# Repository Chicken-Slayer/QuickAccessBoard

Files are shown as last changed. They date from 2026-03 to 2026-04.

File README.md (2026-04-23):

# QuickAccessBoard
This is a 12 key macropad that makes use of a rotary encoder and an OLED display. The body was designed in Fusion, and it uses KMK firmware.

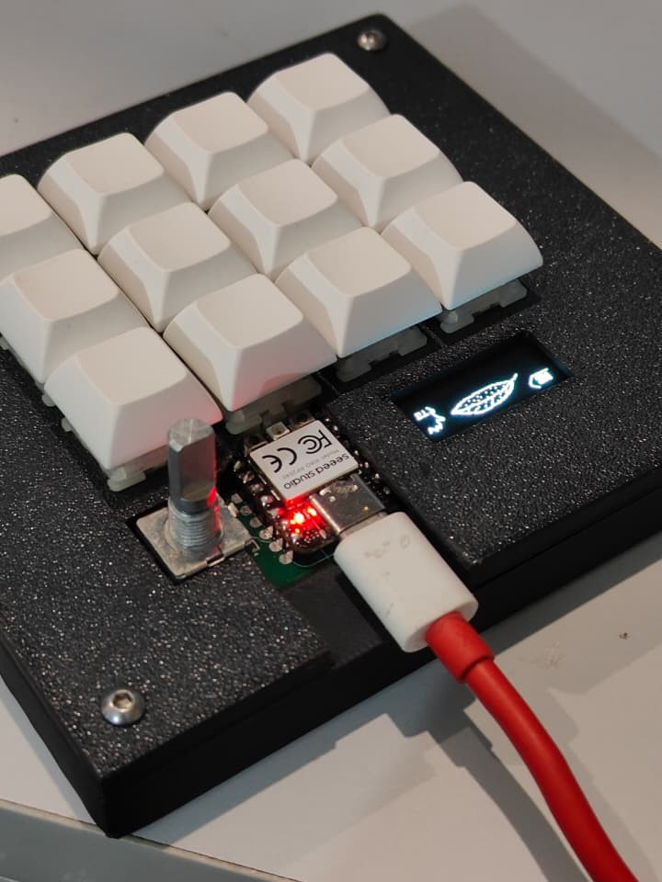
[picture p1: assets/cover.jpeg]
cover


## Features:
- 128x32 OLED Display
- EC11 Rotary Encoder
- 12 Keys

## PCB:
Here's the PCB:

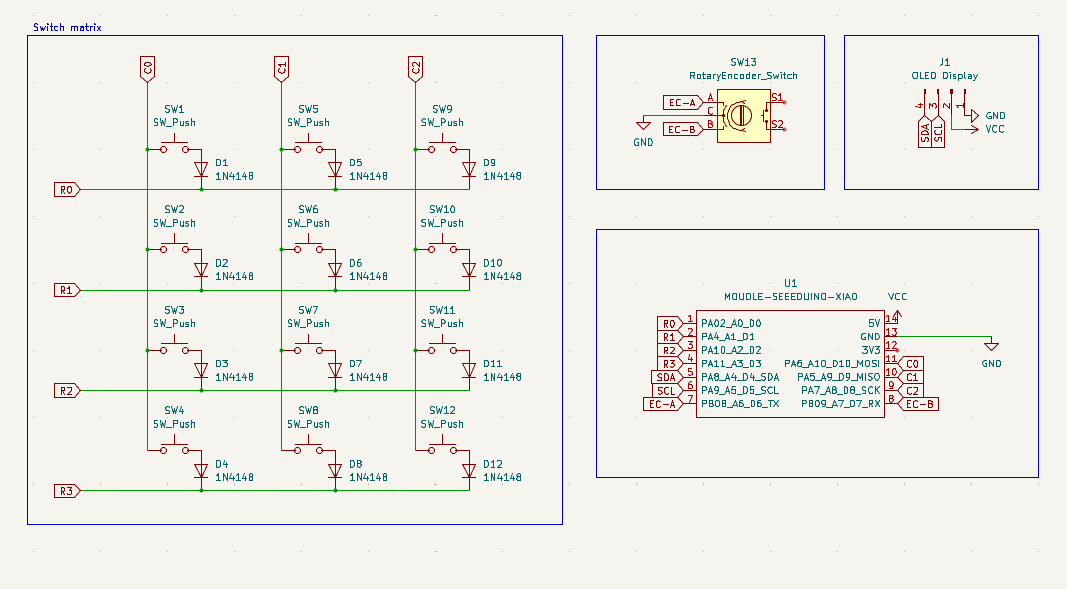
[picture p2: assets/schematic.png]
Schematic


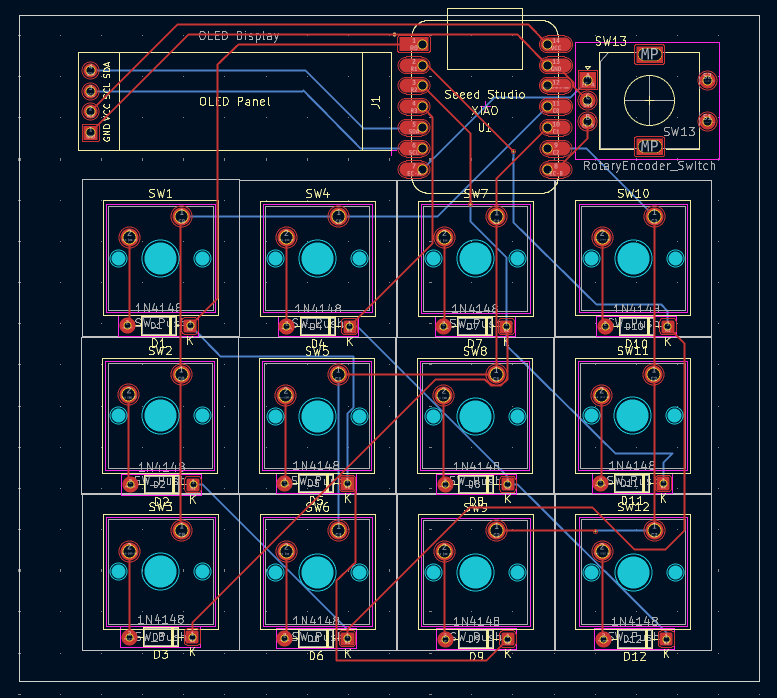
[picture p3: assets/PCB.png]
PCB


## CAD Model:
The case is secured using 4 M3 bolts and heatset inserts. The PCB is held in place in a sandwich arrangement.

It has two separate printed pieces: the base, and the top cover. 

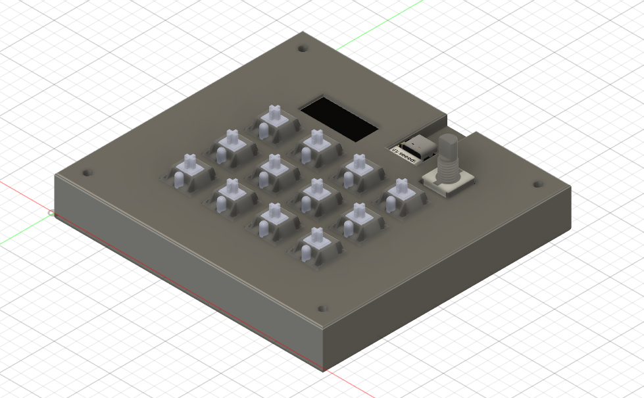
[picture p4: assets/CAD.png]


Made in Fusion.

## Firmware Overview
This hackpad uses [KMK](https://github.com/KMKfw/kmk_firmware) firmware for everything. A key matrix is defined in the code, and various macros are assigned to different keys, as well as media control, brightness controls, and setup for an OLED display. The display by default shows a static image, and goes into sleep mode when the keyboard is not in use. 

It can be easily modified to accomodate other macros and the OLED display image can also be easily swapped out for another, or even an animation quite easily.

## BOM:
Here should be everything you need to make this hackpad

- 12x Cherry MX Switches
- 12x DSA Keycaps
- 4x M3x5x4 Heatset inserts
- 4x M3x16mm SHCS Bolts
- 12x 1N4148 DO-35 Diodes.
- 1x 0.91" 128x32 OLED Display
- 1x EC11 Rotary Encoder
- 1x XIAO RP2040
- 1x Case (2 printed parts)

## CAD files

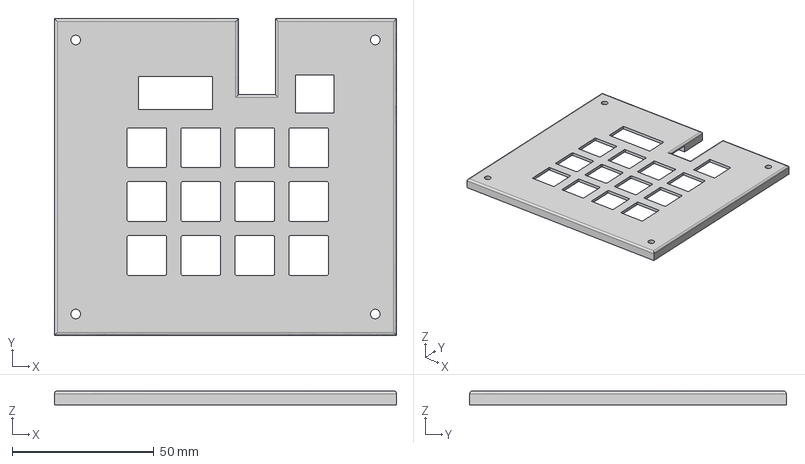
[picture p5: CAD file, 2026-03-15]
production/TOP.step
120.8 x 111.8 x 5.00 mm

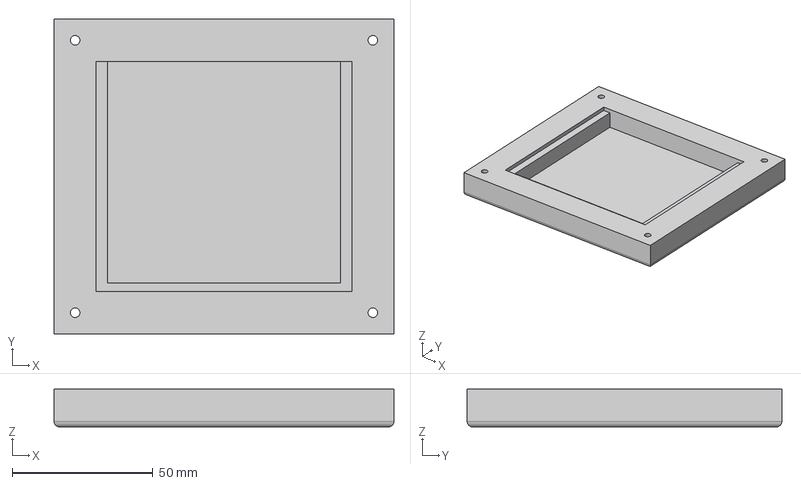
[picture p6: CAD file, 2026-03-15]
production/BOTTOM.step
120.8 x 111.8 x 13.5 mm

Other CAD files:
CAD/QuickAccessBoard.f3z

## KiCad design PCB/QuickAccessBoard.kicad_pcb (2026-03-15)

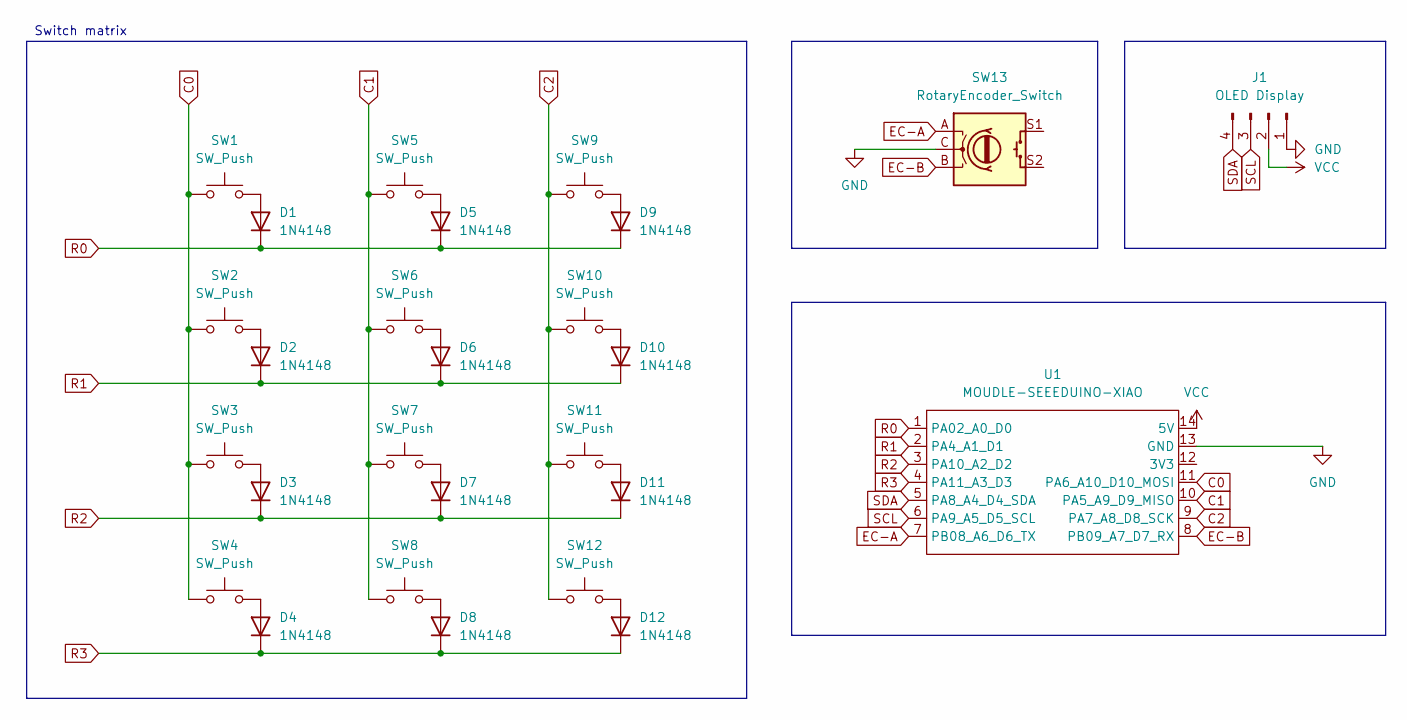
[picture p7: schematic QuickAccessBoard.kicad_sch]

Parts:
D1, D2, D3, D4, D5, D6, D7, D8, D9, D10, D11, D12: 1N4148; D_DO-35_SOD27_P7.62mm_Horizontal
J1: OLED Display; SSD1306-0.91-OLED-4pin-128x32
SW1, SW2, SW3, SW4, SW5, SW6, SW7, SW8, SW9, SW10, SW11, SW12: SW_Push; SW_Cherry_MX_1.00u_PCB
SW13: RotaryEncoder_Switch; RotaryEncoder_Alps_EC11E-Switch_Vertical_H20mm
U1: MOUDLE-SEEEDUINO-XIAO; XIAO-Generic-Hybrid-14P-2.54-21X17.8MM

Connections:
C0: SW1.1, SW2.1, SW3.1, SW4.1, U1.11 (PA6_A10_D10_MOSI)
C1: SW5.1, SW6.1, SW7.1, SW8.1, U1.10 (PA5_A9_D9_MISO)
C2: SW9.1, SW10.1, SW11.1, SW12.1, U1.9 (PA7_A8_D8_SCK)
EC-A: SW13.A, U1.7 (PB08_A6_D6_TX)
EC-B: SW13.B, U1.8 (PB09_A7_D7_RX)
GND: J1.1, SW13.C, U1.13 (GND)
unnamed: D1.2 (A), SW1.2
unnamed: D2.2 (A), SW2.2
unnamed: D3.2 (A), SW3.2
unnamed: D4.2 (A), SW4.2
unnamed: D5.2 (A), SW5.2
unnamed: D6.2 (A), SW6.2
unnamed: D7.2 (A), SW7.2
unnamed: D8.2 (A), SW8.2
unnamed: D9.2 (A), SW9.2
unnamed: D10.2 (A), SW10.2
unnamed: D11.2 (A), SW11.2
unnamed: D12.2 (A), SW12.2
R0: D1.1 (K), D5.1 (K), D9.1 (K), U1.1 (PA02_A0_D0)
R1: D2.1 (K), D6.1 (K), D10.1 (K), U1.2 (PA4_A1_D1)
R2: D3.1 (K), D7.1 (K), D11.1 (K), U1.3 (PA10_A2_D2)
R3: D4.1 (K), D8.1 (K), D12.1 (K), U1.4 (PA11_A3_D3)
SCL: J1.3, U1.6 (PA9_A5_D5_SCL)
SDA: J1.4, U1.5 (PA8_A4_D4_SDA)
VCC: J1.2, U1.14 (5V)

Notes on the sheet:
Switch matrix

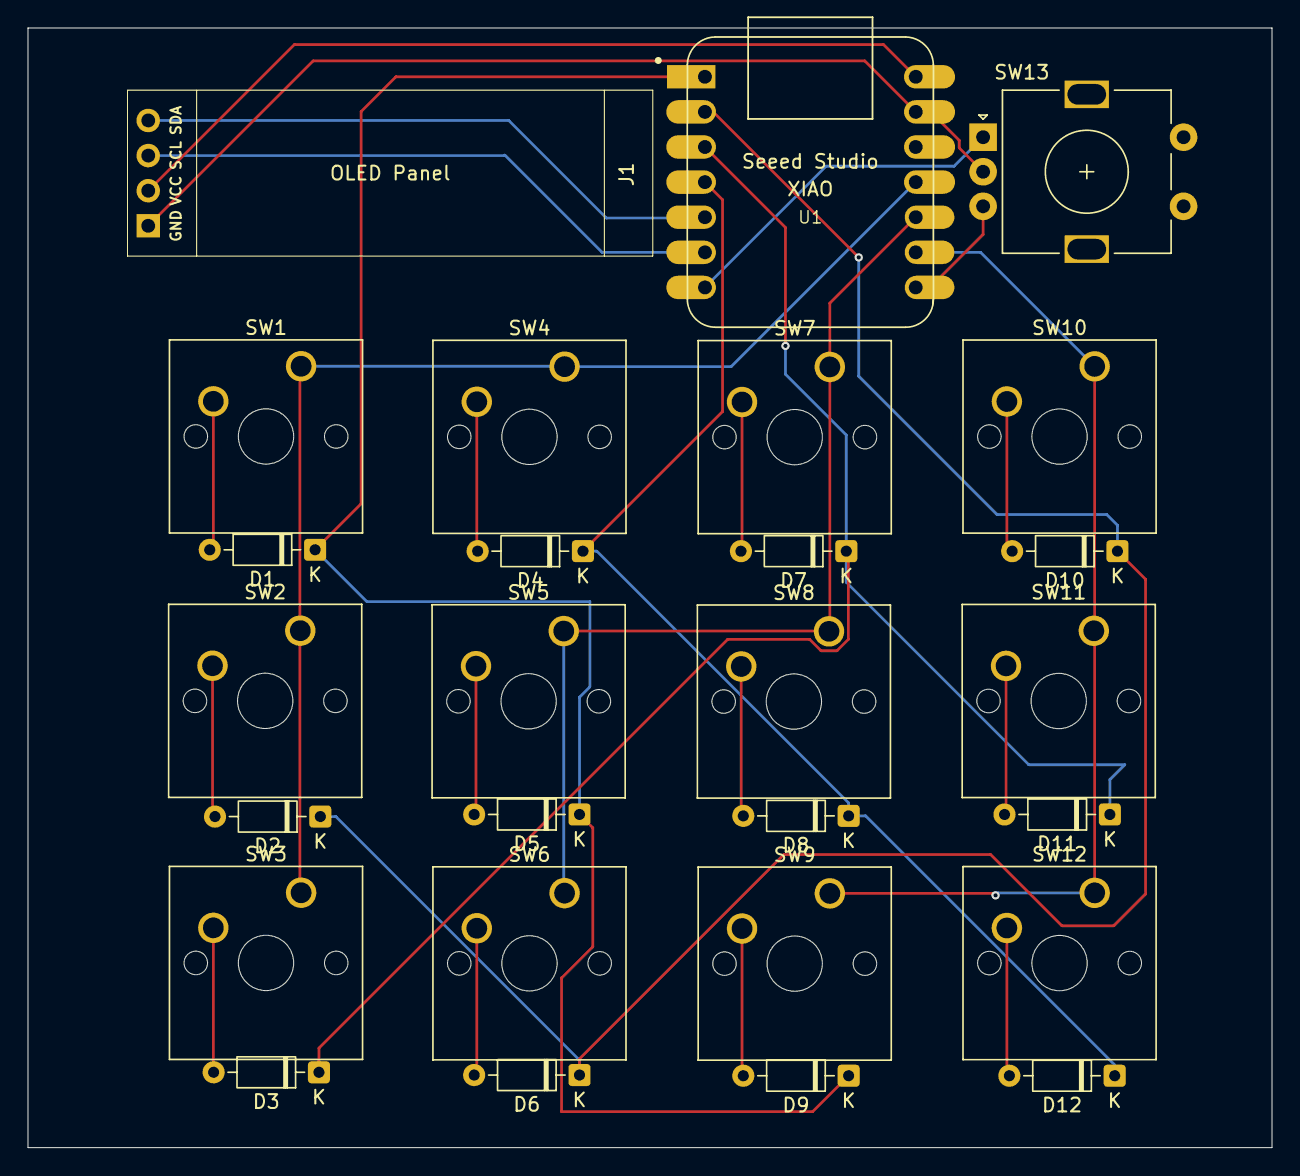
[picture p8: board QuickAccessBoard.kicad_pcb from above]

Board: 2 copper layers, 90.0 x 81.0 mm, 27 parts (0 on the bottom side), 25 nets.

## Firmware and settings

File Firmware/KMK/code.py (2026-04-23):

print("Starting")

import board
import busio

from kmk.kmk_keyboard import KMKKeyboard
from kmk.keys import KC, Key
from kmk.modules.layers import Layers
from kmk.modules.holdtap import HoldTap
from kmk.scanners import DiodeOrientation
from kmk.modules.macros import Macros, UnicodeModeWinC
from kmk.modules.macros import Press, Release, Tap
from kmk.extensions.media_keys import MediaKeys
from kmk.modules.encoder import EncoderHandler
from kmk.extensions.display import Display, TextEntry, ImageEntry
from kmk.extensions.display.ssd1306 import SSD1306
## Keyboard Configuration:

keyboard = KMKKeyboard()
encoder_handler = EncoderHandler()
keyboard.modules.append(encoder_handler)

macros = Macros()
keyboard.modules.append(macros)
keyboard.extensions.append(MediaKeys())
keyboard.col_pins = (board.D10, board.D9, board.D8)
keyboard.row_pins = (board.D0, board.D1, board.D2, board.D3)
keyboard.diode_orientation = DiodeOrientation.COL2ROW

## OLED Configuration:
i2c_bus = busio.I2C(board.SCL, board.SDA)

driver = SSD1306(i2c=i2c_bus)

display = Display(
    # Mandatory:
    display=driver,
    # Optional:
    width=128, # screen size
    height=32, # screen size
    flip = False, # flips your display content
    flip_left = False, # flips your display content on left side split
    flip_right = False, # flips your display content on right side split
    brightness=0.8, # initial screen brightness level
    brightness_step=0.1, # used for brightness increase/decrease keycodes
    dim_time=20, # time in seconds to reduce screen brightness
    dim_target=0.1, # set level for brightness decrease
    off_time=60, # time in seconds to turn off screen
    powersave_dim_time=10, # time in seconds to reduce screen brightness
    powersave_dim_target=0.1, # set level for brightness decrease
    powersave_off_time=30, # time in seconds to turn off screen
)

display.entries = [
    ImageEntry(image="img.bmp", x=0, y=0),
]
keyboard.extensions.append(display)

## Macro Definitions and Keymaps:

macros.unicode_mode = UnicodeModeWinC

## Assign macros to your desired messages here

MSG1 = KC.MACRO("GGWP")
MSG2 = KC.MACRO("Care flank, enemies behind you")
FLIP = KC.MACRO('Hatt')
SHRUG = KC.MACRO('Kya hi kar sakte hai :(')
NICE = KC.MACRO('Nice work team!')
RR = KC.MACRO('https://www.youtube.com/watch?v=dQw4w9WgXcQ')

encoder_handler.pins = (
    # regular direction encoder
    (board.D6, board.D7, None,),
    )

keyboard.keymap = [
    [KC.MUTE, KC.MNXT, KC.MPRV, KC.MPLY, KC.MSTP, MSG1, MSG2, NICE, KC.BRIU, KC.BRID, SHRUG, RR]
]

encoder_handler.map = [ ((KC.VOLU, KC.VOLD),),]

if __name__ == '__main__':
    keyboard.go()

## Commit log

2026-03-15 Structured Project design files
    [QuickAccessBoard.kicad_pcb, QuickAccessBoard.kicad_sch]
2026-03-15 Added production files
    [BOTTOM.step, TOP.step]
2026-03-15 Fixed flaw in PCB
    [QuickAccessBoard.kicad_pcb]
2026-03-16 Fixed README, added CAD source files
    [QuickAccessBoard.f3z]
2026-03-21 Fixed gerbers.zip
2026-04-18 Added OLED, rotary encoder functionality
2026-04-21 Fixed code, added module
    [code.py]
